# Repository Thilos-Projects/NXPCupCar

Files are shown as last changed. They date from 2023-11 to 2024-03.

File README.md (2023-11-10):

# NXPCupCar

Wir lassen Auto fahren  

## Zeitplanung

```mermaid
gantt
dateFormat DD.MM.YYYY
axisFormat  %d.%m.
# excludes 24.12.2023, 25.12.2023, 26.12.2023, 27.12.2023, 28.12.2023, 29.12.2023, 30.12.2023, 31.12.2023, 01.01.2024, 02.01.2024

title Zeitplanung Autonomes Fahrzeug

%% This only works on mermaid.live:

# tickInterval 1week
# weekday monday
# todayMarker off

section 0. Vorbereitung
    Kick-Off : crit, milestone, done, p0, 2023-10-06, 1d

    Meilenstein 0 - Vorbereitung : done, m0, 2023-10-06, 24d

    Konzeptvorstellung : crit, done, milestone, p1, 2023-10-30, 0d

section 1. Fahren I
    Meilenstein 1 - Fahren I : active, m1, after m0, 3w

    Bau Fahrzeug : active, a1, after m0, 2w
    Ansteuerung der Motoren : a2, after a1, 1w

section 2. Fahren II
    Meilenstein 2 - Fahren II : m2, after m1, 2w

    Demo 1 - Irgendwie fahren : crit, milestone, p4, 2023-11-27, 0d

section 3. Kamera I
    Meilenstein 3 - Kamera I : active, m3, after m0, 3w

section 4. Kamera II
    Meilenstein 4 - Kamera II : m4, after m3, 6w

    Entscheidung Erkennungsalgorithmus : a41, after m3, 1w

    Umsetzung der Erkennung : a42, after a41, 5w

    Erkennung Geradeaus : a42a, after a41, 2w
    Erkennung Kurven : a42b, after a42a, 1w
    Erkennung Kreuzung : a42c, after a42b, 1w
    Erkennung Ziellinie : a42d, after a42c, 1w

section 5. Fahren III
    Meilenstein 5 - Fahren III : m5, after m2, 6w

    Sichere 0 fahren : milestone, a52, after a42a a42b, 1d
    Sichere 8 fahren : milestone, a53, after a42c, 1d
    Sicher alles fahren : milestone, a54, after a42d, 1d

    Demo 2 - 0 fahren : crit, milestone, p5, after a52, 1d
    Demo 3 - 8 fahren : crit, milestone, p6, after a53, 1d
    Demo 4 - Alles fahren: crit, milestone, p7, after a54, 1d

section 6. Optimierung
    Meilenstein 6 - Optimierung : m6, after m5, 5w

section Sonstiges
    Weihnachtsferien : p2, 2023-12-23, 11d
    Ender der Vorlesungszeit : milestone, p3, 2024-01-28, 1d
```

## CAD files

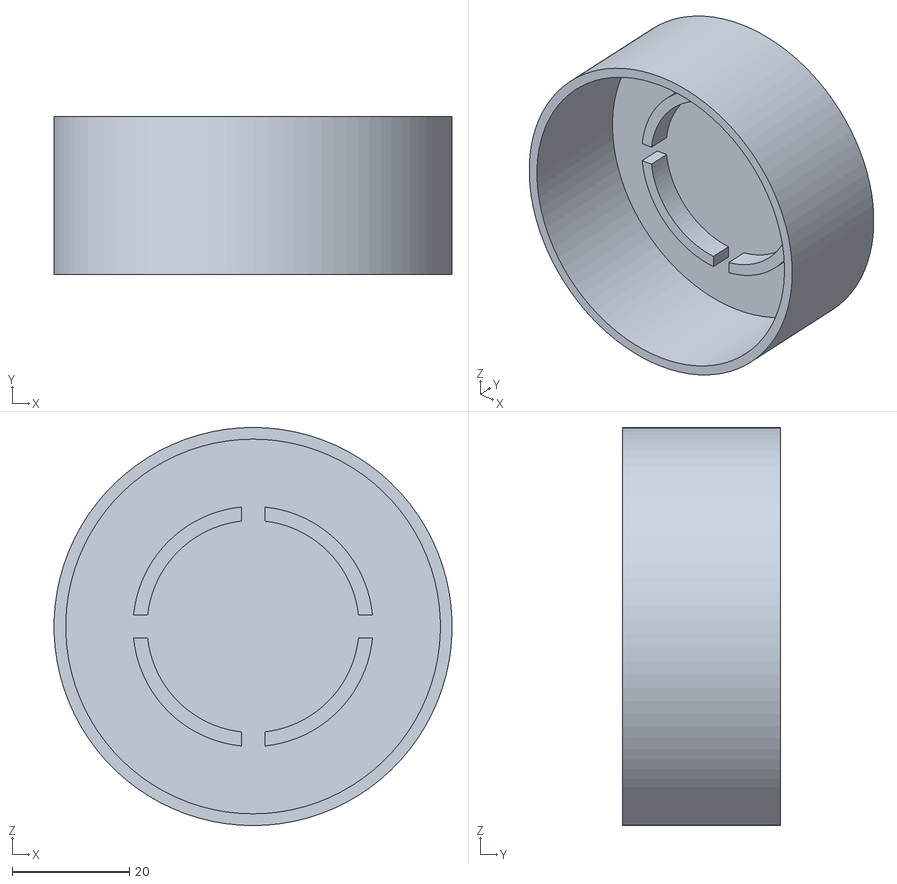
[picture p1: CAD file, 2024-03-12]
hardware/NXPModellRadHülle.stl
68.0 x 27.0 x 68.0

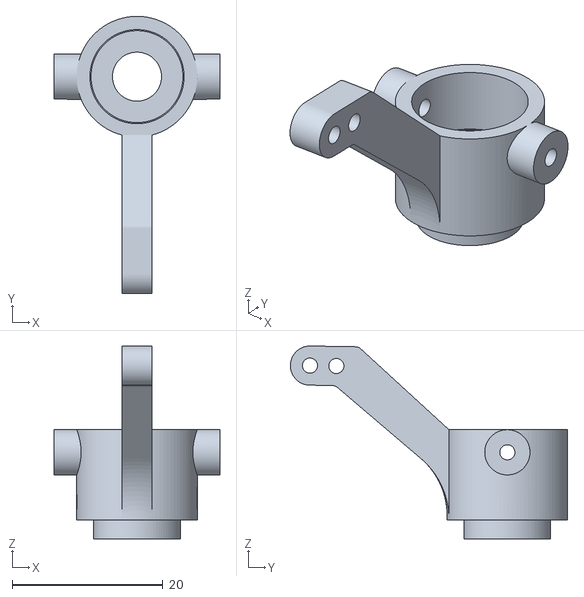
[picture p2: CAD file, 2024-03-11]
hardware/NXPModellForderRadHalterung.stl
22.0 x 36.8 x 25.6

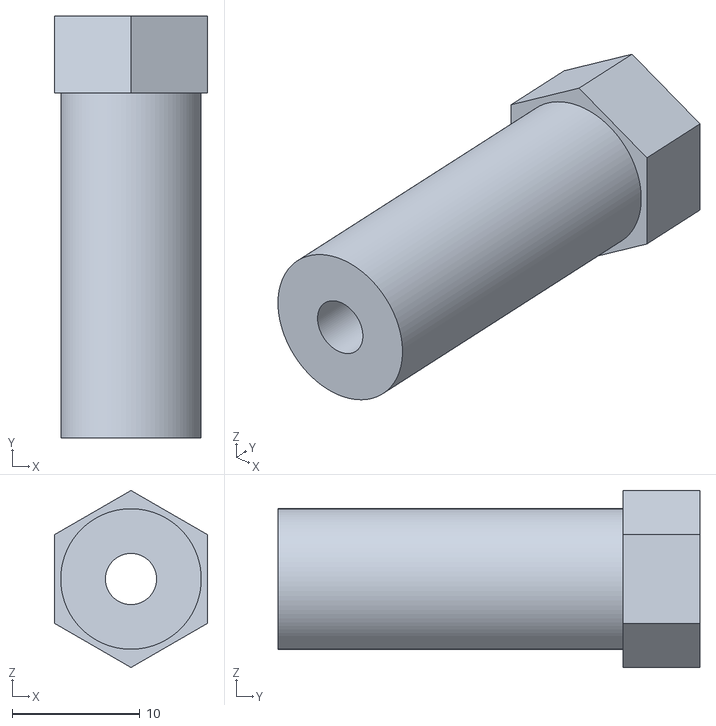
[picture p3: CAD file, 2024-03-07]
hardware/NXPModellRadAchsenHalter_2.stl
12.0 x 33.0 x 13.9

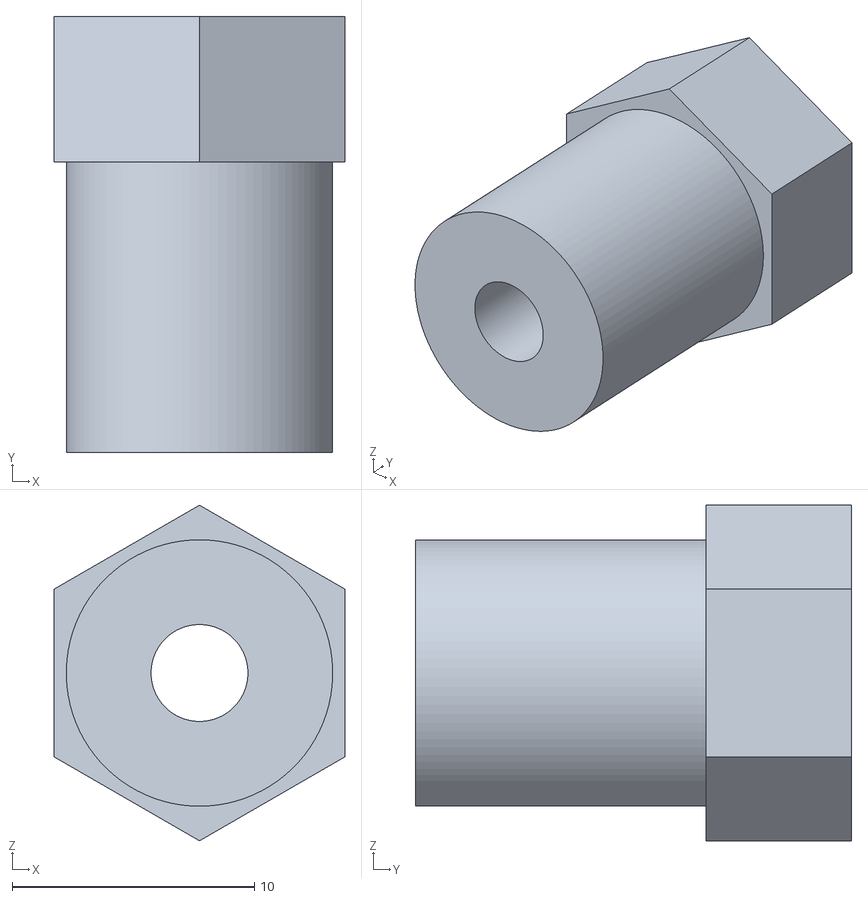
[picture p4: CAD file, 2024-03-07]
hardware/NXPModellRadAchsenHalter.stl
12.0 x 18.0 x 13.9

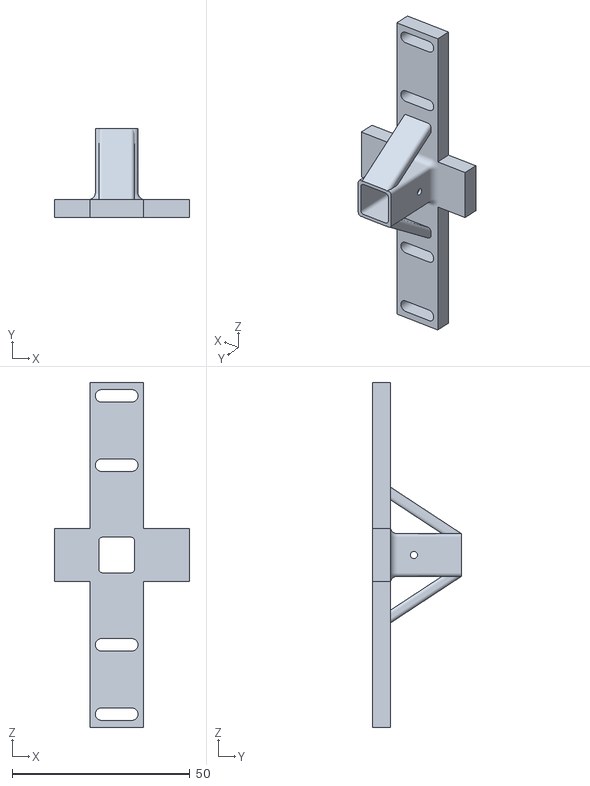
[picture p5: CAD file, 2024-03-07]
hardware/NXPModellKammeraTurmHalter.stl
38.0 x 25.0 x 97.0

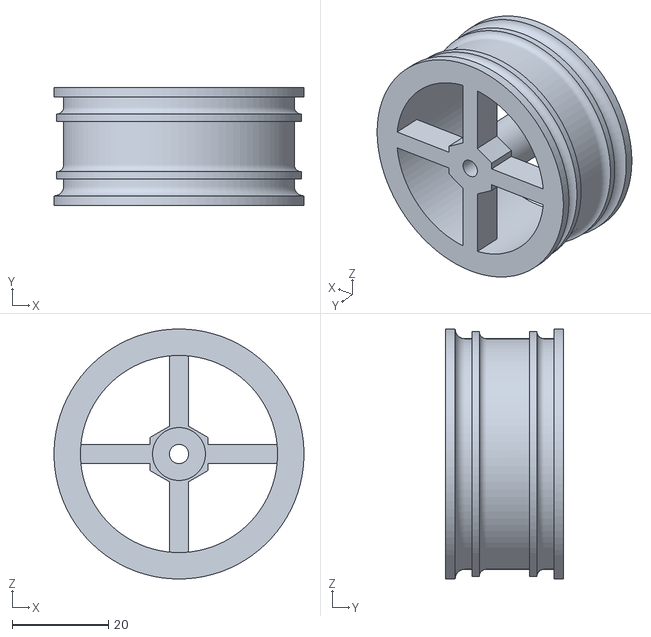
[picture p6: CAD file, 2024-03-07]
hardware/NXPModellRad.stl
52.0 x 24.5 x 52.0

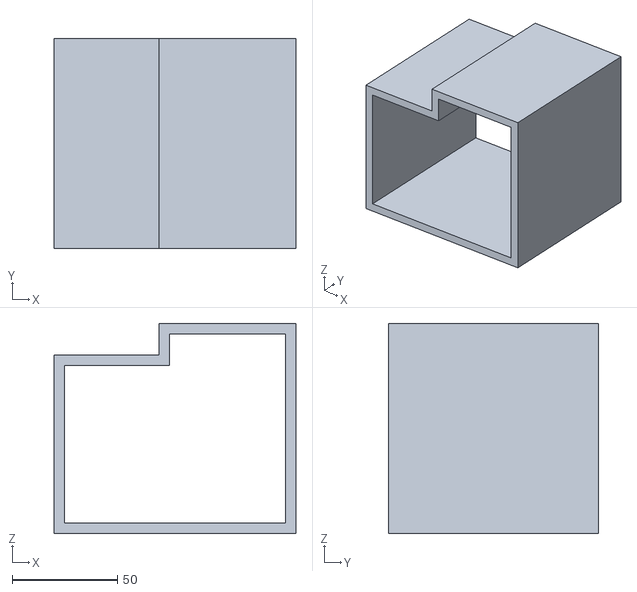
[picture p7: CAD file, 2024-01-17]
hardware/NXPModellKisteLinks.stl
115.0 x 100.0 x 100.0

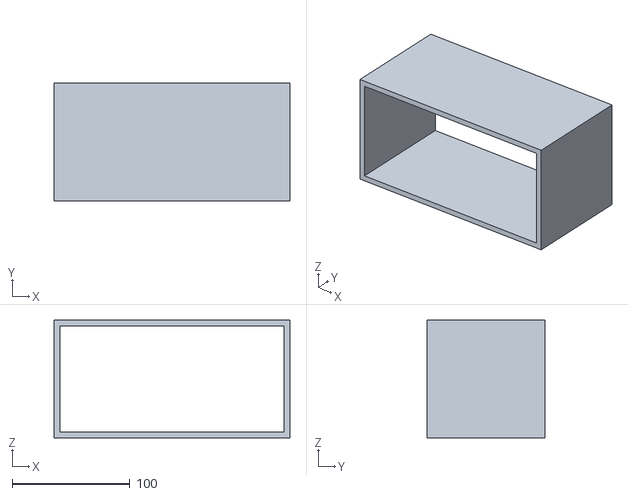
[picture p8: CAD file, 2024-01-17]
hardware/NXPModellKisteMitte.stl
200.0 x 100.0 x 100.0

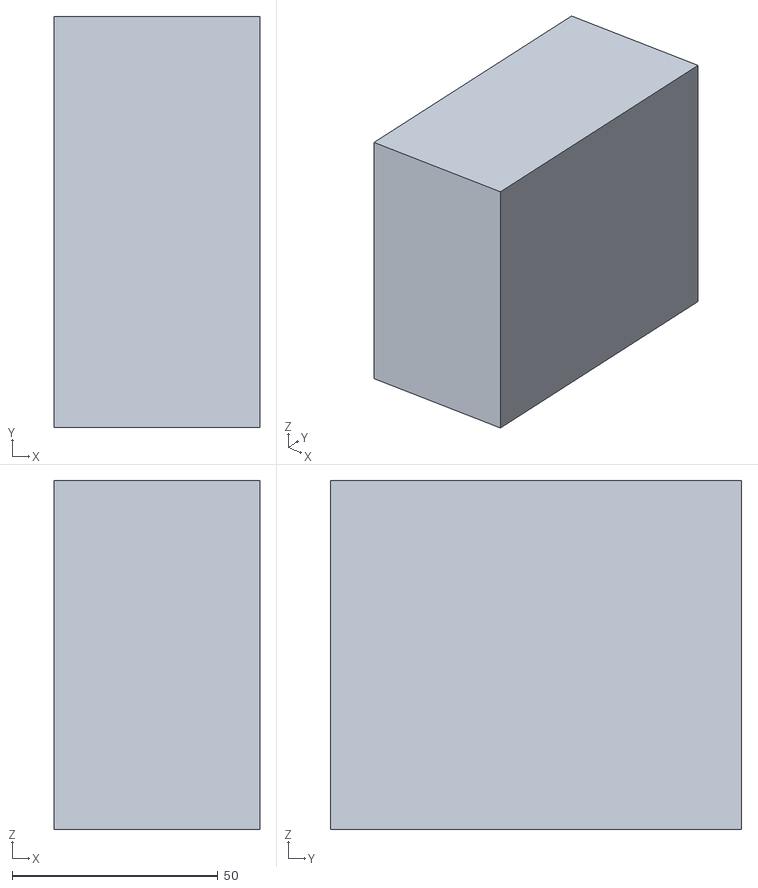
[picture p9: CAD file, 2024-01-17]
hardware/NXPModellKisteRechts.stl
50.0 x 100.0 x 85.0

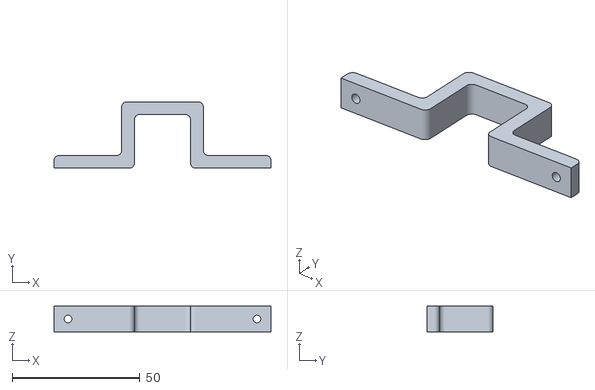
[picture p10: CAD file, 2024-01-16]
hardware/NXPModellJLinkHalter.stl
85.0 x 26.0 x 10.0

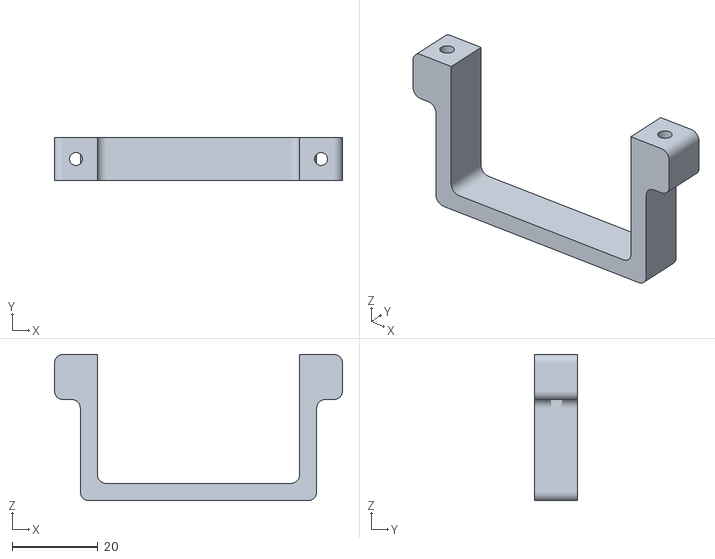
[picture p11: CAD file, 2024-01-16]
hardware/NXPModellBatterieHalter_V3.stl
67.0 x 10.0 x 34.0

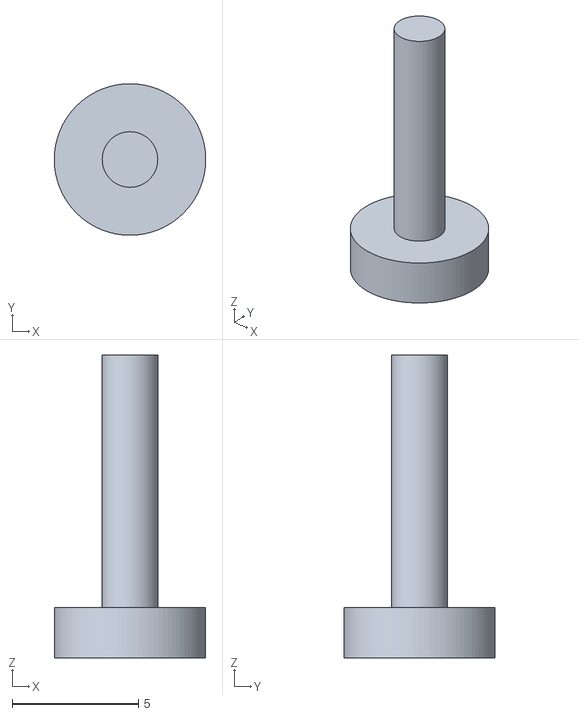
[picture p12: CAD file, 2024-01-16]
hardware/NXPModellLenkhalter.stl
6.00 x 6.00 x 12.0

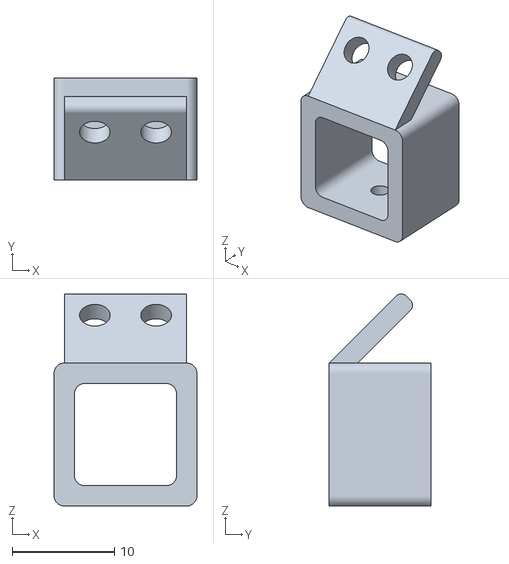
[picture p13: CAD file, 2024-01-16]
hardware/NXPModellKammeraHalter.stl
14.0 x 10.0 x 20.8

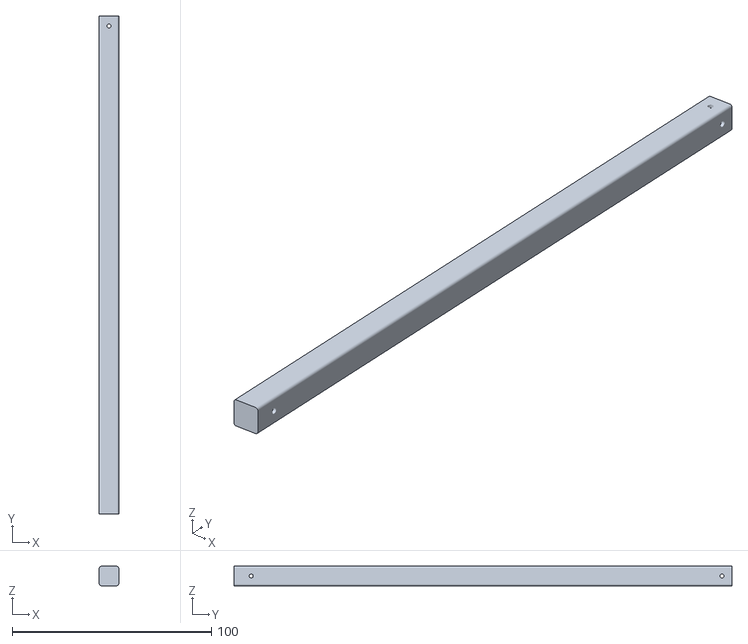
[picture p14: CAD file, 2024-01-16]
hardware/NXPModellKammeraTurm.stl
9.80 x 250.0 x 9.80

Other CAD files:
hardware/NXPModellHallHalterKeil.stl
hardware/NXPModellKammeraHalter_30.stl
hardware/NXPModellHallHalter.stl
hardware/NXPModellKammeraHalter_15.stl
hardware/NXPModellBatterieHalter.stl
hardware/NXPModellBatterieHalter_V2.stl
hardware/NXPModellMagnetSchablone.stl

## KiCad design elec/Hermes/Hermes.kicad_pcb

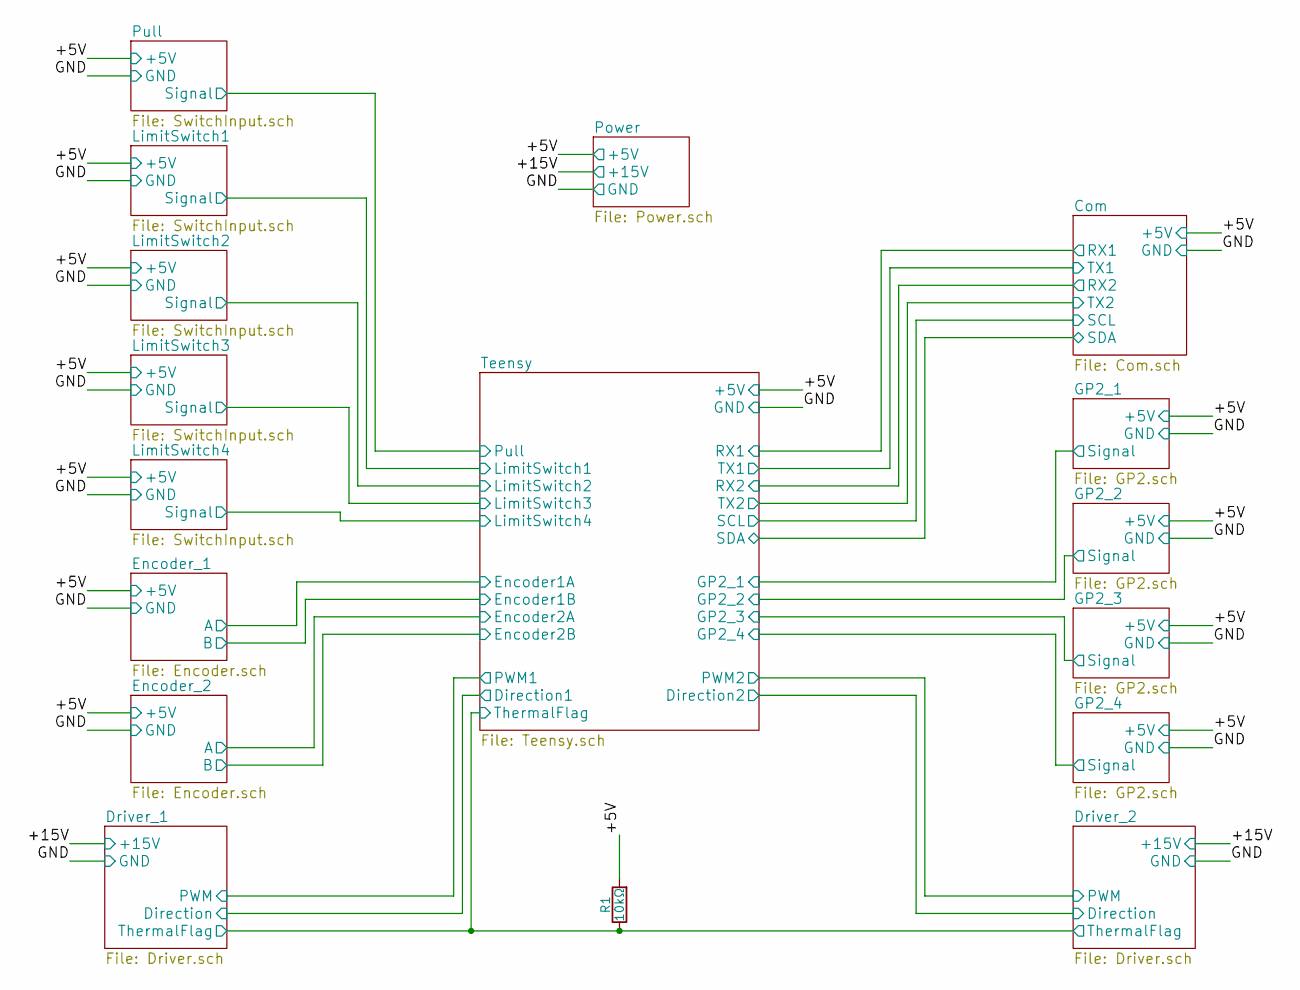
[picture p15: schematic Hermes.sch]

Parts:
R1: 10kΩ; R_CMS1206

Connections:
/Com/+5V: R1.2; also elsewhere on the board
/Driver_1/ThermalFlag: R1.1; also elsewhere on the board

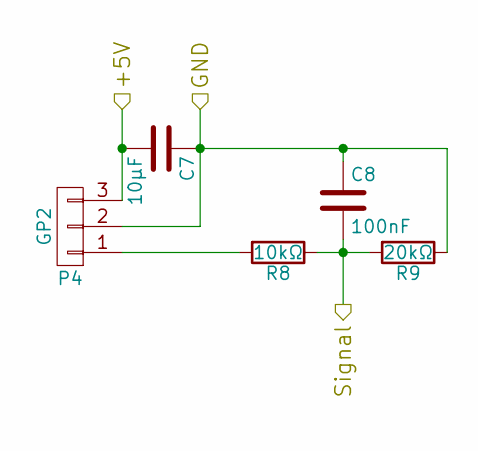
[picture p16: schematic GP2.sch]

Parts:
C1: 10µF; C_CMS1210
C2: 100nF; C_CMS0603
P1: GP2; Conn_01x03
R2: 10kΩ; R_CMS1206
R3: 20kΩ; R_CMS1206

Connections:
/Com/+5V: C1.2, P1.3; also elsewhere on the board
/Com/GND: C1.1, C2.1, P1.2, R3.1; also elsewhere on the board
/Teensy/GP2_1: C2.2, R2.1, R3.2; also elsewhere on the board
unnamed: P1.1, R2.2

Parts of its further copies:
C3, C5, C7: 10µF; C_CMS1210
C4, C6, C8: 100nF; C_CMS0603
P2, P3, P4: GP2; Conn_01x03
R4, R6, R8: 10kΩ; R_CMS1206
R5, R7, R9: 20kΩ; R_CMS1206

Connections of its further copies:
/Com/+5V: C3.2, C5.2, C7.2, P2.3, P3.3, P4.3; also elsewhere on the board
/Com/GND: C3.1, C4.1, C5.1, C6.1, C7.1, C8.1, P2.2, P3.2, P4.2, R5.1, R7.1, R9.1; also elsewhere on the board
/Teensy/GP2_2: C4.2, R4.1, R5.2; also elsewhere on the board
/Teensy/GP2_3: C6.2, R6.1, R7.2; also elsewhere on the board
/Teensy/GP2_4: C8.2, R8.1, R9.2; also elsewhere on the board
unnamed: P2.1, R4.2
unnamed: P3.1, R6.2
unnamed: P4.1, R8.2

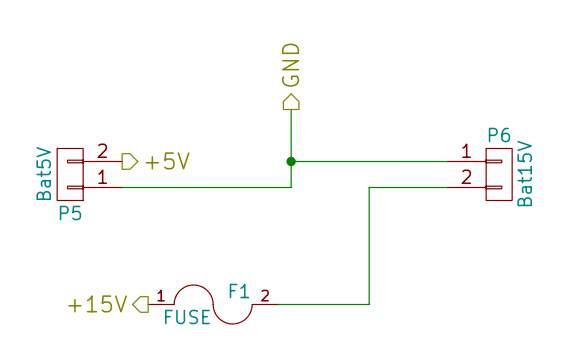
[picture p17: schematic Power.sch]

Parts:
F1: FUSE; Fuse
P5: Bat5V; Conn_01x02
P6: Bat15V; Power_Conn_01x02

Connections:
/Com/+5V: P5.2; also elsewhere on the board
/Com/GND: P5.1, P6.1; also elsewhere on the board
/Driver_1/+15V: F1.1; also elsewhere on the board
unnamed: F1.2, P6.2

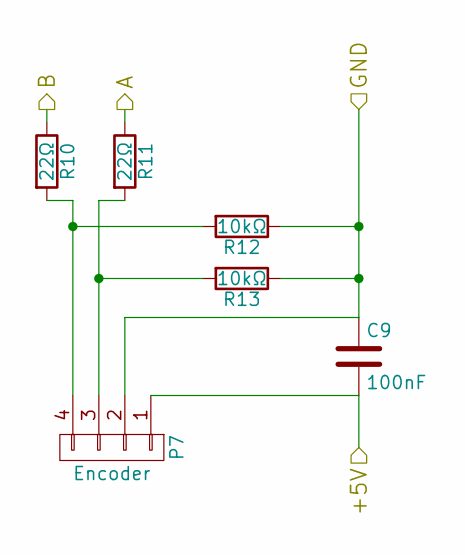
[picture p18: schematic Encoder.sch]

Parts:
C9: 100nF; C_CMS0603
P7: Encoder; Conn_01x04
R10, R11: 22Ω; R_CMS1206
R12, R13: 10kΩ; R_CMS1206

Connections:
/Com/+5V: C9.2, P7.1; also elsewhere on the board
/Com/GND: C9.1, P7.2, R12.1, R13.1; also elsewhere on the board
/Encoder_1/A: R11.1; also elsewhere on the board
/Encoder_1/B: R10.1; also elsewhere on the board
unnamed: P7.3, R11.2, R13.2
unnamed: P7.4, R10.2, R12.2

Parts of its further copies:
C10: 100nF; C_CMS0603
P8: Encoder; Conn_01x04
R14, R15: 22Ω; R_CMS1206
R16, R17: 10kΩ; R_CMS1206

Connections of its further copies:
/Com/+5V: C10.2, P8.1; also elsewhere on the board
/Com/GND: C10.1, P8.2, R16.1, R17.1; also elsewhere on the board
/Encoder_2/A: R15.1; also elsewhere on the board
/Encoder_2/B: R14.1; also elsewhere on the board
unnamed: P8.3, R15.2, R17.2
unnamed: P8.4, R14.2, R16.2

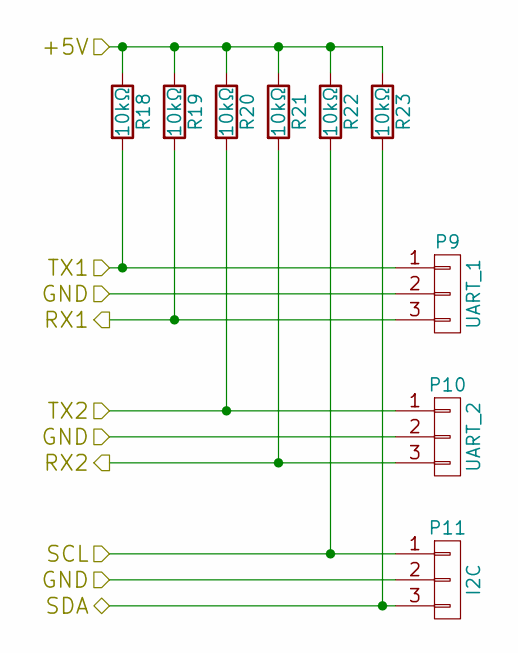
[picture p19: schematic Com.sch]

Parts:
P9: UART_1; Conn_01x03
P10: UART_2; Conn_01x03
P11: I2C; Conn_01x03
R18, R19, R20, R21, R22, R23: 10kΩ; R_CMS1206

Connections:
/Com/+5V: R18.1, R19.1, R20.1, R21.1, R22.1, R23.1; also elsewhere on the board
/Com/GND: P9.2, P10.2, P11.2; also elsewhere on the board
/Com/RX1: P9.3, R19.2; also elsewhere on the board
/Com/RX2: P10.3, R21.2; also elsewhere on the board
/Com/SCL: P11.1, R22.2; also elsewhere on the board
/Com/SDA: P11.3, R23.2; also elsewhere on the board
/Com/TX1: P9.1, R18.2; also elsewhere on the board
/Com/TX2: P10.1, R20.2; also elsewhere on the board

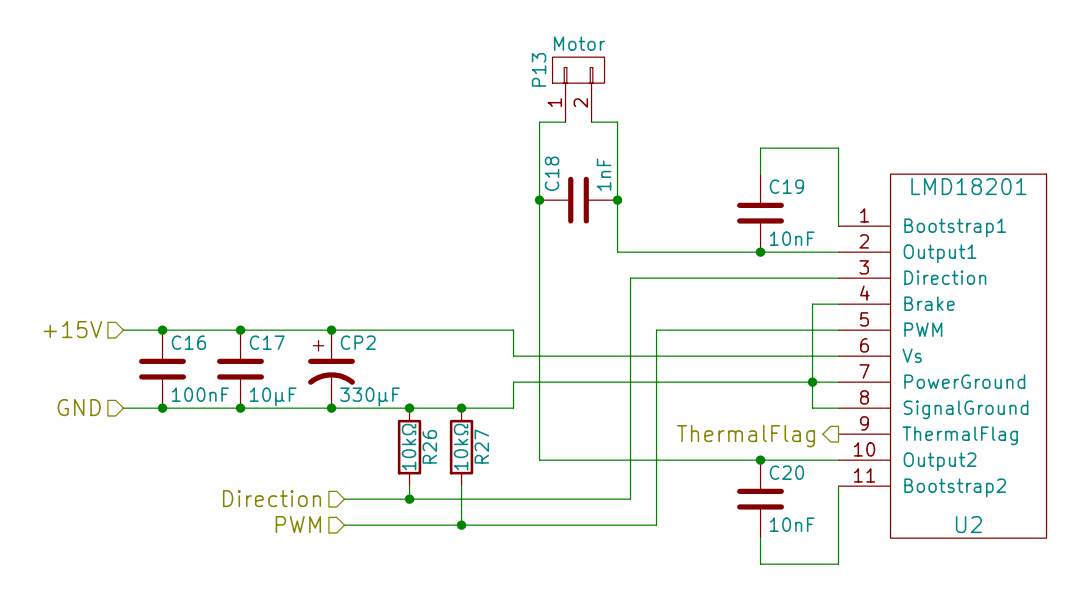
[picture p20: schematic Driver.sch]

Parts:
C11: 100nF; C_CMS0603
C12: 10µF; C_CMS1210
C13: 1nF; C_CMS0603
C14, C15: 10nF; C_CMS0603
CP1: 330µF; C_Radial
P12: Motor; Power_Conn_01x02
R24, R25: 10kΩ; R_CMS1206
U1: LMD18201

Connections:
/Com/GND: C11.2, C12.2, CP1.2, R24.1, R25.1, U1.4 (Brake), U1.7 (PowerGround), U1.8 (SignalGround); also elsewhere on the board
/Driver_1/+15V: C11.1, C12.1, CP1.1, U1.6 (Vs); also elsewhere on the board
/Driver_1/Direction: R24.2, U1.3 (Direction); also elsewhere on the board
/Driver_1/PWM: R25.2, U1.5 (PWM); also elsewhere on the board
/Driver_1/ThermalFlag: U1.9 (ThermalFlag); also elsewhere on the board
unnamed: C13.1, C15.1, P12.1, U1.10 (Output2)
unnamed: C13.2, C14.2, P12.2, U1.2 (Output1)
unnamed: C14.1, U1.1 (Bootstrap1)
unnamed: C15.2, U1.11 (Bootstrap2)

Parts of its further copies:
C16: 100nF; C_CMS0603
C17: 10µF; C_CMS1210
C18: 1nF; C_CMS0603
C19, C20: 10nF; C_CMS0603
CP2: 330µF; C_Radial
P13: Motor; Power_Conn_01x02
R26, R27: 10kΩ; R_CMS1206
U2: LMD18201

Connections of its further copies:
/Com/GND: C16.2, C17.2, CP2.2, R26.1, R27.1, U2.4 (Brake), U2.7 (PowerGround), U2.8 (SignalGround); also elsewhere on the board
/Driver_1/+15V: C16.1, C17.1, CP2.1, U2.6 (Vs); also elsewhere on the board
/Driver_1/ThermalFlag: U2.9 (ThermalFlag); also elsewhere on the board
/Driver_2/Direction: R26.2, U2.3 (Direction); also elsewhere on the board
/Driver_2/PWM: R27.2, U2.5 (PWM); also elsewhere on the board
unnamed: C18.1, C20.1, P13.1, U2.10 (Output2)
unnamed: C18.2, C19.2, P13.2, U2.2 (Output1)
unnamed: C19.1, U2.1 (Bootstrap1)
unnamed: C20.2, U2.11 (Bootstrap2)

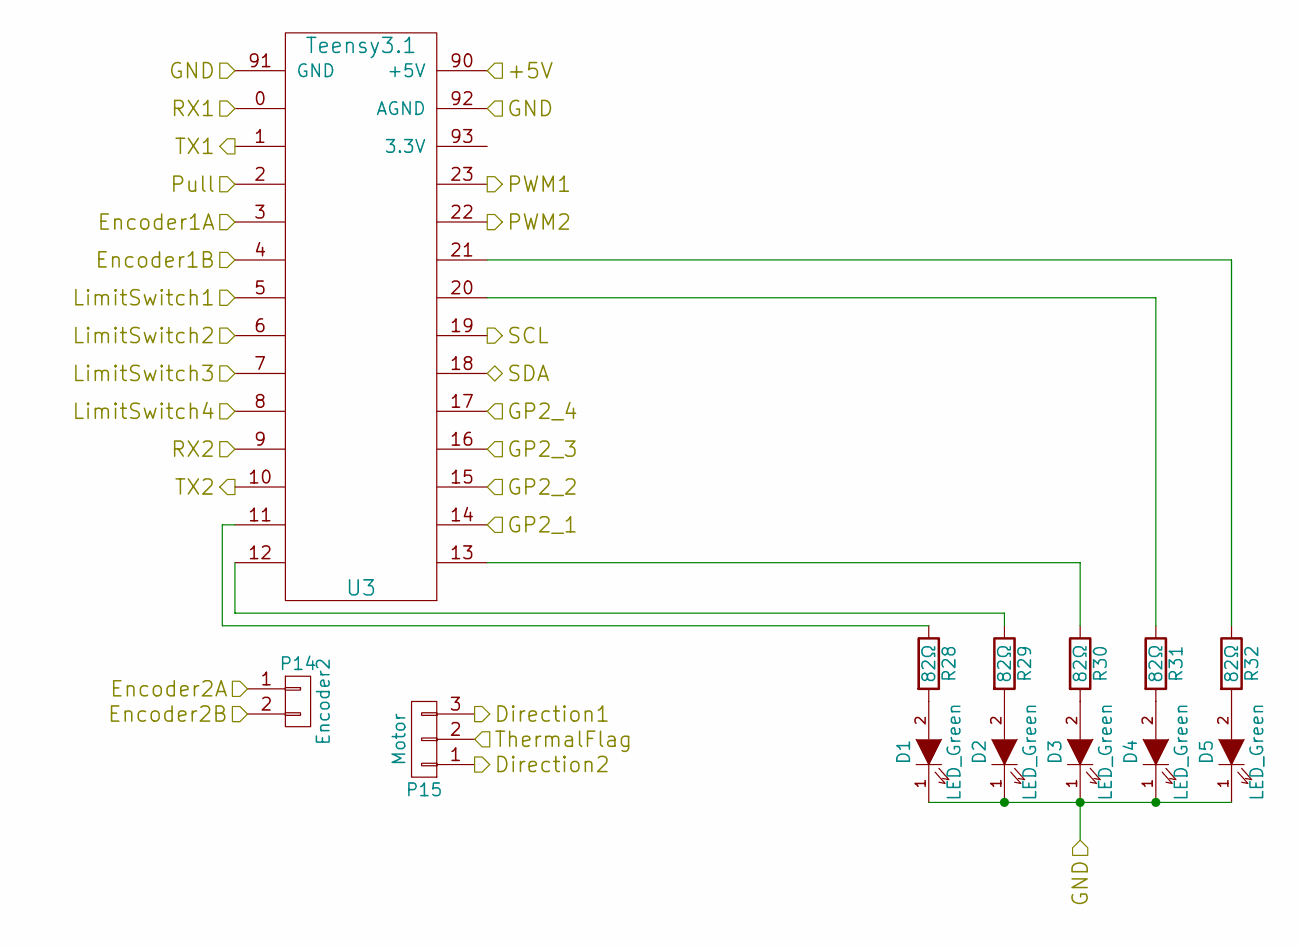
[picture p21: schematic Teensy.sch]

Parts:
D1, D2, D3, D4, D5: LED_Green; LED_Green_CMS
P14: Encoder2; Conn_01x02
P15: Motor; Conn_01x03
R28, R29, R30, R31, R32: 82Ω; R_CMS1206
U3: Teensy3.1

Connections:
/Com/+5V: U3.90 (+5V); also elsewhere on the board
/Com/GND: D1.1 (K), D2.1 (K), D3.1 (K), D4.1 (K), D5.1 (K), U3.91 (GND), U3.92 (AGND); also elsewhere on the board
/Com/RX1: U3.0; also elsewhere on the board
/Com/RX2: U3.9; also elsewhere on the board
/Com/SCL: U3.19; also elsewhere on the board
/Com/SDA: U3.18; also elsewhere on the board
/Com/TX1: U3.1; also elsewhere on the board
/Com/TX2: U3.10; also elsewhere on the board
/Driver_1/Direction: P15.3; also elsewhere on the board
/Driver_1/PWM: U3.23; also elsewhere on the board
/Driver_1/ThermalFlag: P15.2; also elsewhere on the board
/Driver_2/Direction: P15.1; also elsewhere on the board
/Driver_2/PWM: U3.22; also elsewhere on the board
/Encoder_1/A: U3.3; also elsewhere on the board
/Encoder_1/B: U3.4; also elsewhere on the board
/Encoder_2/A: P14.1; also elsewhere on the board
/Encoder_2/B: P14.2; also elsewhere on the board
/Teensy/GP2_1: U3.14; also elsewhere on the board
/Teensy/GP2_2: U3.15; also elsewhere on the board
/Teensy/GP2_3: U3.16; also elsewhere on the board
/Teensy/GP2_4: U3.17; also elsewhere on the board
/Teensy/LimitSwitch1: U3.5; also elsewhere on the board
/Teensy/LimitSwitch2: U3.6; also elsewhere on the board
/Teensy/LimitSwitch3: U3.7; also elsewhere on the board
/Teensy/LimitSwitch4: U3.8; also elsewhere on the board
/Teensy/Pull: U3.2; also elsewhere on the board
unnamed: D1.2 (A), R28.2
unnamed: D2.2 (A), R29.2
unnamed: D3.2 (A), R30.2
unnamed: D4.2 (A), R31.2
unnamed: D5.2 (A), R32.2
unnamed: R28.1, U3.11
unnamed: R29.1, U3.12
unnamed: R30.1, U3.13
unnamed: R31.1, U3.20
unnamed: R32.1, U3.21

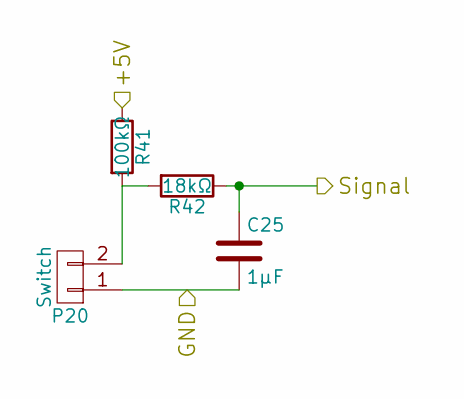
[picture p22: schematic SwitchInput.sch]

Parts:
C21: 1µF; C_CMS0603
P16: Switch; Conn_01x02
R33: 100kΩ; R_CMS1206
R34: 18kΩ; R_CMS1206

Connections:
/Com/+5V: R33.1; also elsewhere on the board
/Com/GND: C21.2, P16.1; also elsewhere on the board
/Teensy/Pull: C21.1, R34.1; also elsewhere on the board
unnamed: P16.2, R33.2, R34.2

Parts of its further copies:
C22, C23, C24, C25: 1µF; C_CMS0603
P17, P18, P19, P20: Switch; Conn_01x02
R35, R37, R39, R41: 100kΩ; R_CMS1206
R36, R38, R40, R42: 18kΩ; R_CMS1206

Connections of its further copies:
/Com/+5V: R35.1, R37.1, R39.1, R41.1; also elsewhere on the board
/Com/GND: C22.2, C23.2, C24.2, C25.2, P17.1, P18.1, P19.1, P20.1; also elsewhere on the board
/Teensy/LimitSwitch1: C22.1, R36.1; also elsewhere on the board
/Teensy/LimitSwitch2: C23.1, R38.1; also elsewhere on the board
/Teensy/LimitSwitch3: C24.1, R40.1; also elsewhere on the board
/Teensy/LimitSwitch4: C25.1, R42.1; also elsewhere on the board
unnamed: P17.2, R35.2, R36.2
unnamed: P18.2, R37.2, R38.2
unnamed: P19.2, R39.2, R40.2
unnamed: P20.2, R41.2, R42.2

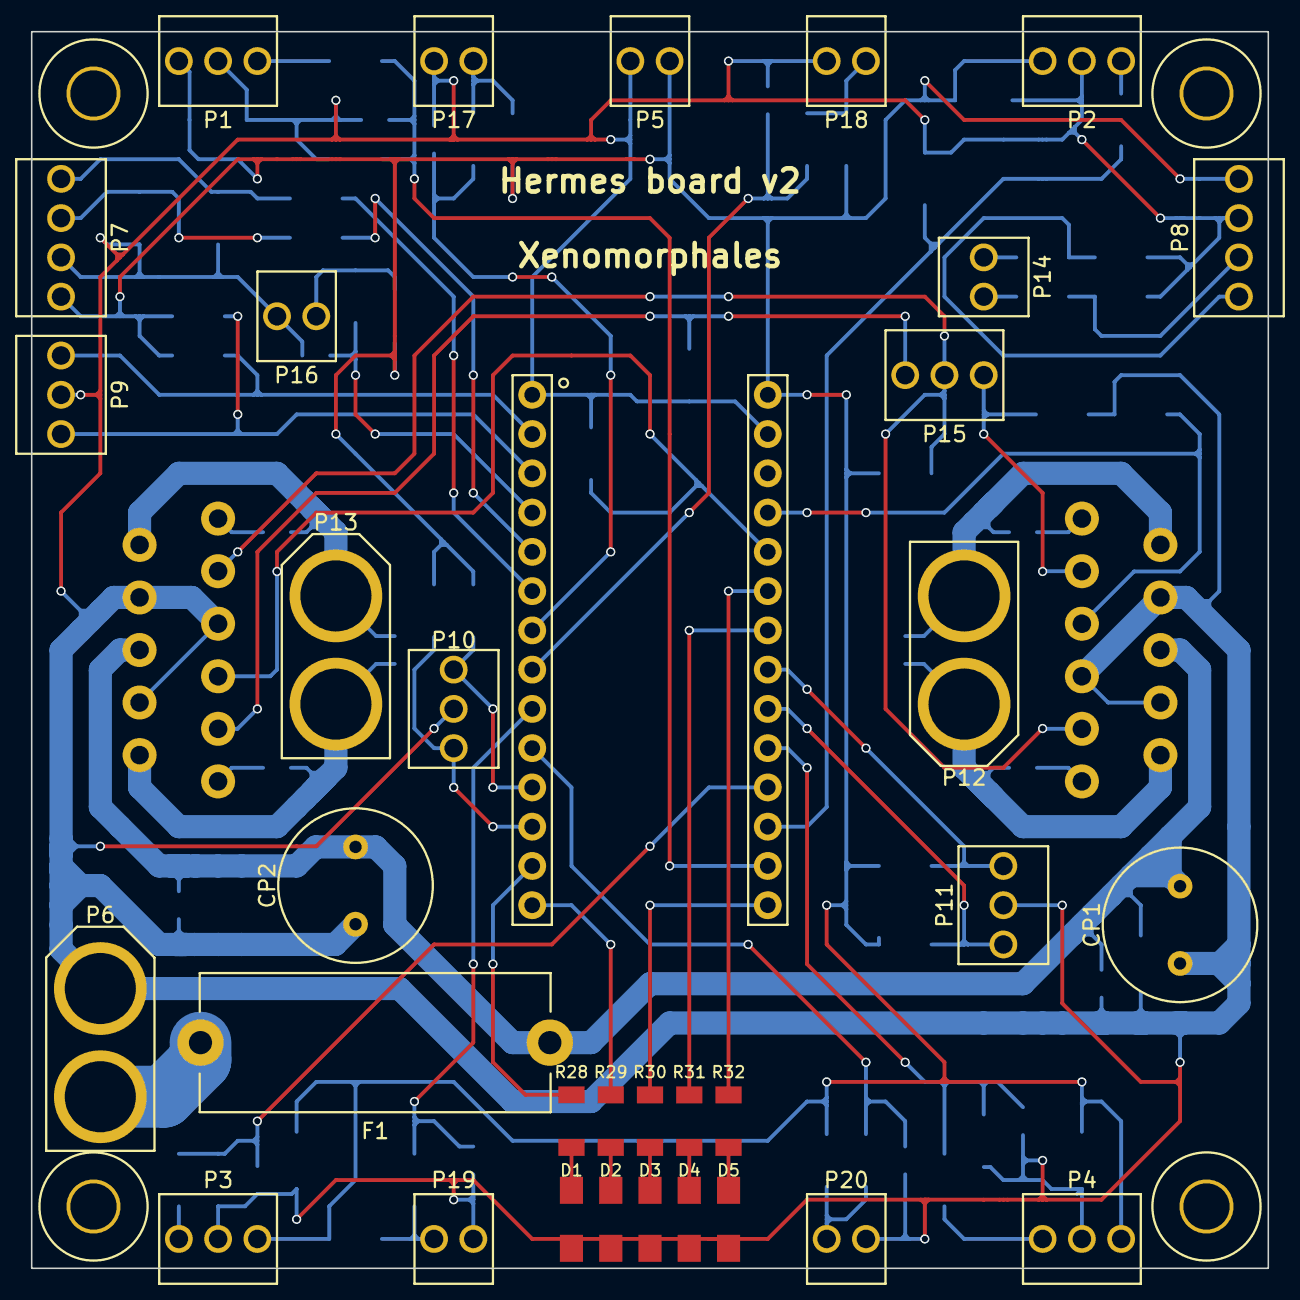
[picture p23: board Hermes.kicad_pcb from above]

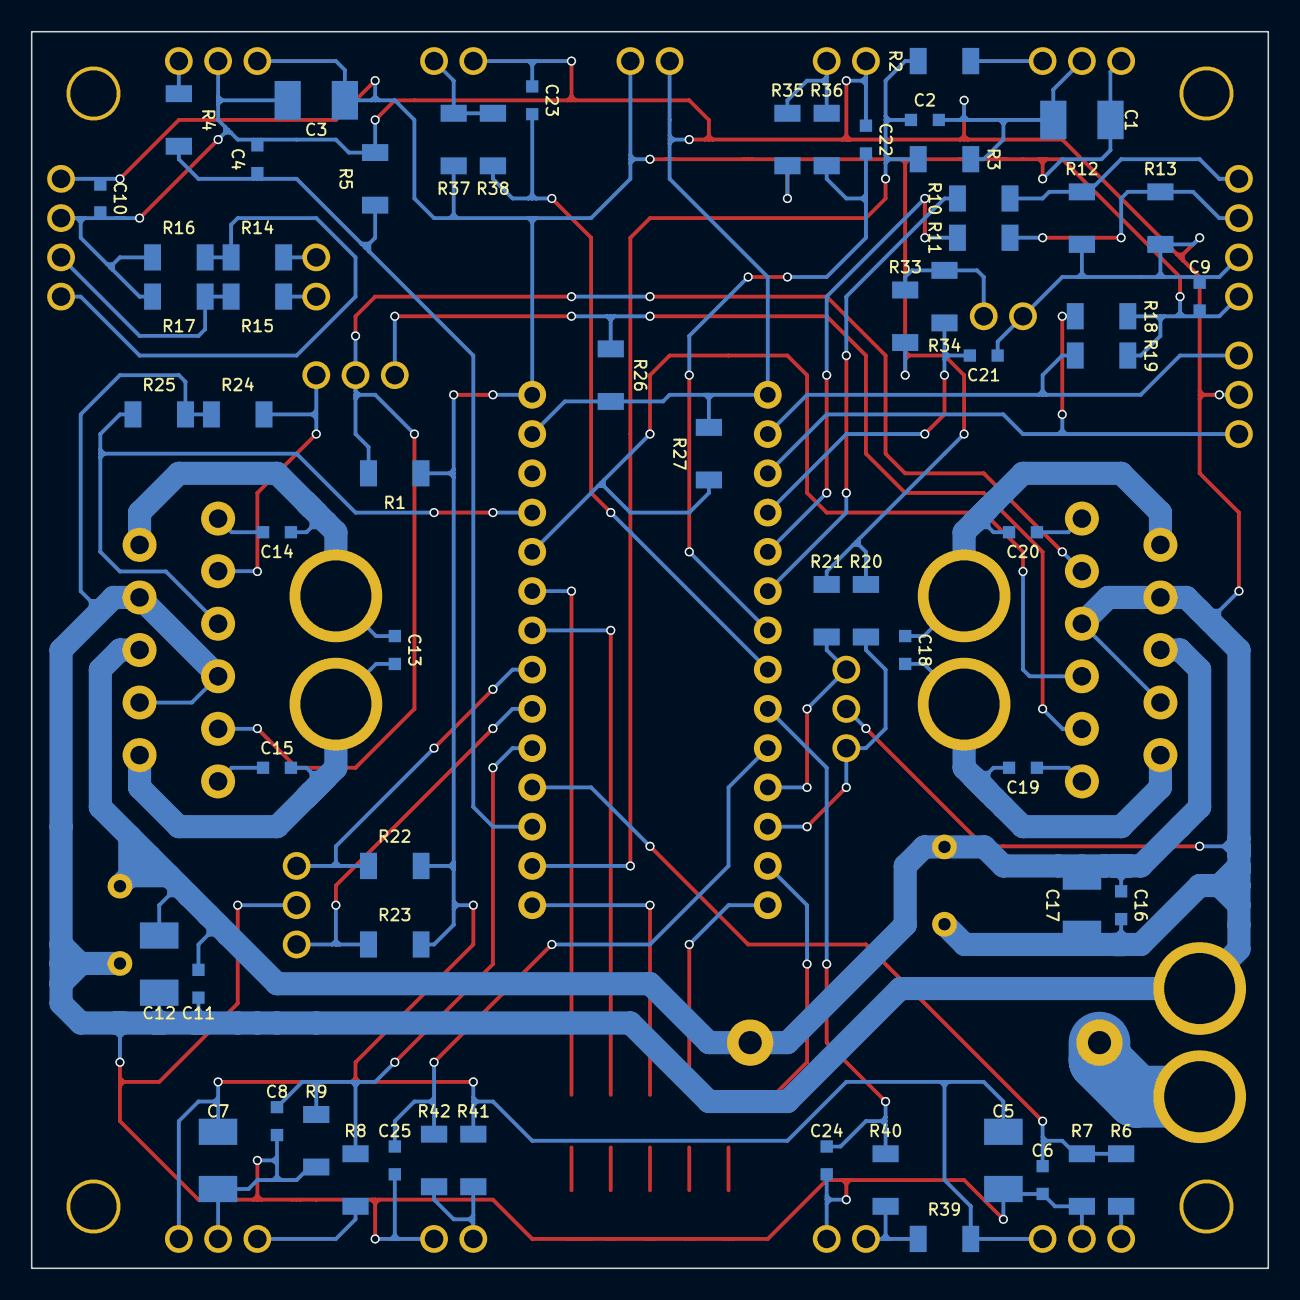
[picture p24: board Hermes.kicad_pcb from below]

Board: 2 copper layers, 80.0 x 80.0 mm, 98 parts (62 on the bottom side), 59 nets.

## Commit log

2023-11-26 Hardware Stuff
    [NXPModellBatterieHalter.stl]
2024-01-16 3DModelle Kamera Rad Akku
    [NXPModellBatterieHalter_V2.stl, NXPModellHallHalter.stl, NXPModellHallHalterKeil.stl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]
2024-01-16 Mehr stuf
    [NXPModellBatterieHalter_V3.stl, NXPModellJLinkHalter.stl, NXPModellKammeraTurmHalter.stl]
2024-03-07 Neue 3d modelle
    [NXPModellForderRadHalterung.stl, NXPModellKammeraTurmHalter.stl, NXPModellRad.stl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]
2024-03-07 New system test not slower than other
    [NXPModellForderRadHalterung.stl]
2024-03-11 Size korrection
    [NXPModellForderRadHalterung.stl]
